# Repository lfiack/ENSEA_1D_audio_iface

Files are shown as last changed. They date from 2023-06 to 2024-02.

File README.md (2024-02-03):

# ENSEA_1D_audio_iface
Interface audio (carte son) pour les TP de systèmes numériques en 1D à l'ENSEA

## Make the project work
This project uses a submodule for the KiCAD library. To get it properly, use the `--recursive` option when cloning the repo :
```
git clone --recursive git@github.com:lfiack/ENSEA_1D_audio_iface.git
```

If you forgot the `--recursive` option (as I do quite often), you can type the following command :
```
git submodule update --init --recursive
```

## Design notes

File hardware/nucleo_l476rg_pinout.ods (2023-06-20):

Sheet: Pinout
101 | PC10 | 102 | PC11 | 201 | PC9 | 202 | PC8
103 | PC12 | 104 | PD2 | 203 | PB8 | 204 | PC6
105 | VDD | 106 | E5V | 205 | PB9 | 206 | PC5
107 | BOOT0 | 108 | GND | 207 | AVDD | 208 | U5V
109 | NC | 110 | NC | 209 | GND | 210 | NC
111 | NC | 112 | IOREF | 211 | PA5 | 212 | PA12
113 | PA13 | 114 | RESET | 213 | PA6 | 214 | PA11
115 | PA14 | 116 | +3V3 | 215 | PA7 | 216 | PB12
117 | PA15 | 118 | +5V | 217 | PB6 | 218 | PB11
119 | GND | 120 | GND | 219 | PC7 | 220 | GND
121 | PB7 | 122 | GND | 221 | PA9 | 222 | PB2
123 | PC13 | 124 | VIN | 223 | PA8 | 224 | PB1
125 | PC14 | 126 | NC | 225 | PB10 | 226 | PB15
127 | PC15 | 128 | PA0 | 227 | PB4 | 228 | PB14
129 | PH0 | 130 | PA1 | 229 | PB5 | 230 | PB13
131 | PH1 | 132 | PA4 | 231 | PB3 | 232 | AGND
133 | VBAT | 134 | PB0 | 233 | PA10 | 234 | PC4
135 | PC2 | 136 | PC1 | 235 | PA2 | 236 | NC
137 | PC3 | 138 | PC0 | 237 | PA3 | 238 | NC

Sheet: Sorted
116 | +3V3
118 | +5V
232 | AGND
207 | AVDD
107 | BOOT0
106 | E5V
108 | GND
119 | GND
120 | GND
122 | GND
209 | GND
220 | GND
112 | IOREF
114 | RESET
208 | U5V
133 | VBAT
105 | VDD
124 | VIN
109 | NC
110 | NC
111 | NC
126 | NC
210 | NC
236 | NC
238 | NC
128 | PA0
130 | PA1
235 | PA2
237 | PA3
132 | PA4
211 | PA5
213 | PA6
215 | PA7
223 | PA8
221 | PA9
233 | PA10
214 | PA11
212 | PA12
113 | PA13
115 | PA14
117 | PA15
134 | PB0
224 | PB1
222 | PB2
231 | PB3
227 | PB4
229 | PB5
217 | PB6
121 | PB7
203 | PB8
205 | PB9
225 | PB10
218 | PB11
216 | PB12
230 | PB13
228 | PB14
226 | PB15
138 | PC0
136 | PC1
135 | PC2
137 | PC3
234 | PC4
206 | PC5
204 | PC6
219 | PC7
202 | PC8
201 | PC9
101 | PC10
102 | PC11
103 | PC12
123 | PC13
125 | PC14
127 | PC15
104 | PD2
129 | PH0
131 | PH1

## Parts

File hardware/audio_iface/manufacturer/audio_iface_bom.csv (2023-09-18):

Designator | Comment | Footprint | LCSC Part #
R301, R401, R402 | 5.1k | Resistor_SMD:R_0402_1005Metric | C2906948
D506, D507, D514, D515 | ORANGE | LED_SMD:LED_0603_1608Metric | C965801
U301 | SGTL5000XNAA3 | Package_DFN_QFN:QFN-32-1EP_5x5mm_P0.5mm_EP3.6x3.6mm | C511764
J303 | HP | Connector_Audio:Jack_3.5mm_PJ320D_Horizontal | C431535
J302 | LINEOUT | Connector_Audio:Jack_3.5mm_PJ320D_Horizontal | C431535
J301 | LINEIN | Connector_Audio:Jack_3.5mm_PJ320D_Horizontal | C431535
J401 | USB_C_Receptacle_USB2.0 | Connector_USB:USB_C_Receptacle_HRO_TYPE-C-31-M-12 | C165948
U501 | MCP23S17-E/SO | Package_SO:SOIC-28W_7.5x17.9mm_P1.27mm | C145413
D501, D502, D503, D504, D505, D509, D510, D511, D512, D513 | GREEN | LED_SMD:LED_0603_1608Metric | C72043
C301, C302, C304, C309, C310, C311, C312 | 1uF | Capacitor_SMD:C_0603_1608Metric | C15849
U401 | USBLC6-2SC6 | Package_TO_SOT_SMD:SOT-23-6 | C7519
D508, D516 | RED | LED_SMD:LED_0603_1608Metric | C2286
C303, C305, C306, C307, C308, C501 | 100nF | Capacitor_SMD:C_0402_1005Metric | C1525
U201 | NUCLEO_L476RG | WITNS:ST_NUCLEO_64
TP307 | HP GND | Connector_Pin:Pin_D1.1mm_L8.5mm_W2.5mm_FlatFork
TP303, TP305, TP308 | L | Connector_Pin:Pin_D1.1mm_L8.5mm_W2.5mm_FlatFork
TP302, TP304, TP306 | R | Connector_Pin:Pin_D1.1mm_L8.5mm_W2.5mm_FlatFork
TP301 | MIC | Connector_Pin:Pin_D1.1mm_L8.5mm_W2.5mm_FlatFork
TP205 | GND | Connector_Pin:Pin_D1.1mm_L8.5mm_W2.5mm_FlatFork
TP204 | TX | Connector_Pin:Pin_D1.1mm_L8.5mm_W2.5mm_FlatFork
TP203 | RX | Connector_Pin:Pin_D1.1mm_L8.5mm_W2.5mm_FlatFork
TP202 | +3.3VA | Connector_Pin:Pin_D1.1mm_L8.5mm_W2.5mm_FlatFork
TP201 | +3.3V | Connector_Pin:Pin_D1.1mm_L8.5mm_W2.5mm_FlatFork
TP112 | SDA | Connector_Pin:Pin_D1.1mm_L8.5mm_W2.5mm_FlatFork
TP111 | SCL | Connector_Pin:Pin_D1.1mm_L8.5mm_W2.5mm_FlatFork
TP110 | DOUT | Connector_Pin:Pin_D1.1mm_L8.5mm_W2.5mm_FlatFork
TP109 | DIN | Connector_Pin:Pin_D1.1mm_L8.5mm_W2.5mm_FlatFork
TP108 | LRCLK | Connector_Pin:Pin_D1.1mm_L8.5mm_W2.5mm_FlatFork
TP107 | SCLK | Connector_Pin:Pin_D1.1mm_L8.5mm_W2.5mm_FlatFork
TP106 | MCLK | Connector_Pin:Pin_D1.1mm_L8.5mm_W2.5mm_FlatFork
TP105 | nCS | Connector_Pin:Pin_D1.1mm_L8.5mm_W2.5mm_FlatFork
TP104 | SCK | Connector_Pin:Pin_D1.1mm_L8.5mm_W2.5mm_FlatFork
TP103 | MOSI | Connector_Pin:Pin_D1.1mm_L8.5mm_W2.5mm_FlatFork
TP102 | MISO | Connector_Pin:Pin_D1.1mm_L8.5mm_W2.5mm_FlatFork
TP101 | nRESET | Connector_Pin:Pin_D1.1mm_L8.5mm_W2.5mm_FlatFork
R506, R507, R508, R514, R515, R516 | 680 | Resistor_SMD:R_0603_1608Metric
R501, R502, R503, R504, R505, R509, R510, R511, R512, R513 | 560 | Resistor_SMD:R_0603_1608Metric
R302, R303 | 1.5k | Resistor_SMD:R_0402_1005Metric
MK301 | Microphone | WITNS:Electret_ABM-713-RC
J201 | UART | Connector_JST:JST_XH_S3B-XH-A_1x03_P2.50mm_Horizontal

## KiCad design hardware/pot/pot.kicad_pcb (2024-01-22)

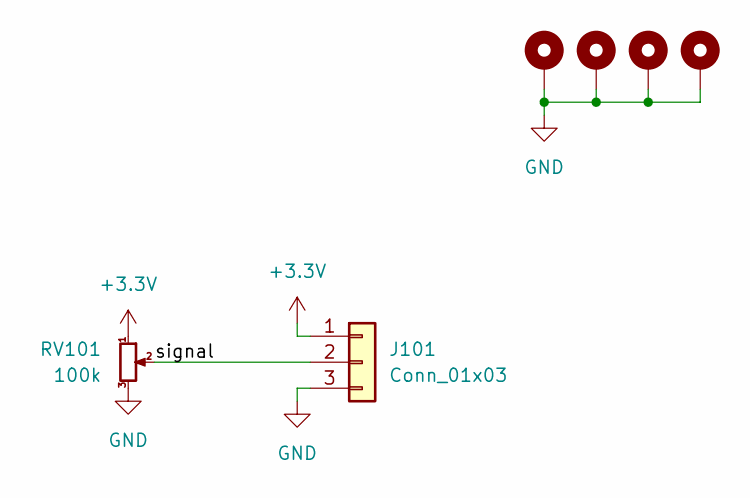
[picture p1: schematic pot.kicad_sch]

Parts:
H101, H102, H103, H104: MountingHole_Pad; MountingHole_3.2mm_M3_Pad
J101: Conn_01x03; JST_XH_S3B-XH-A-1_1x03_P2.50mm_Horizontal
RV101: 100k; Potentiometer_Alpha_RD901F-40-00D_Single_Vertical

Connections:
+3.3V: J101.1, RV101.1
/signal: J101.2, RV101.2
GND: H101.1, H102.1, H103.1, H104.1, J101.3, RV101.3

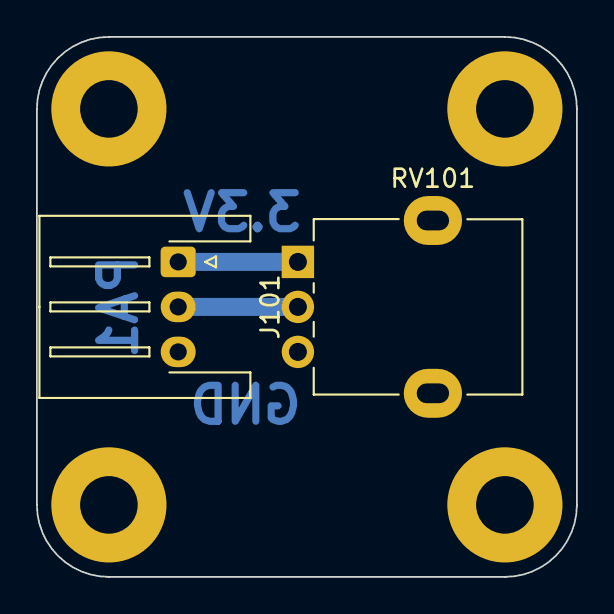
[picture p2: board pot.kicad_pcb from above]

Board: 2 copper layers, 30.0 x 30.0 mm, 6 parts (0 on the bottom side), 3 nets.

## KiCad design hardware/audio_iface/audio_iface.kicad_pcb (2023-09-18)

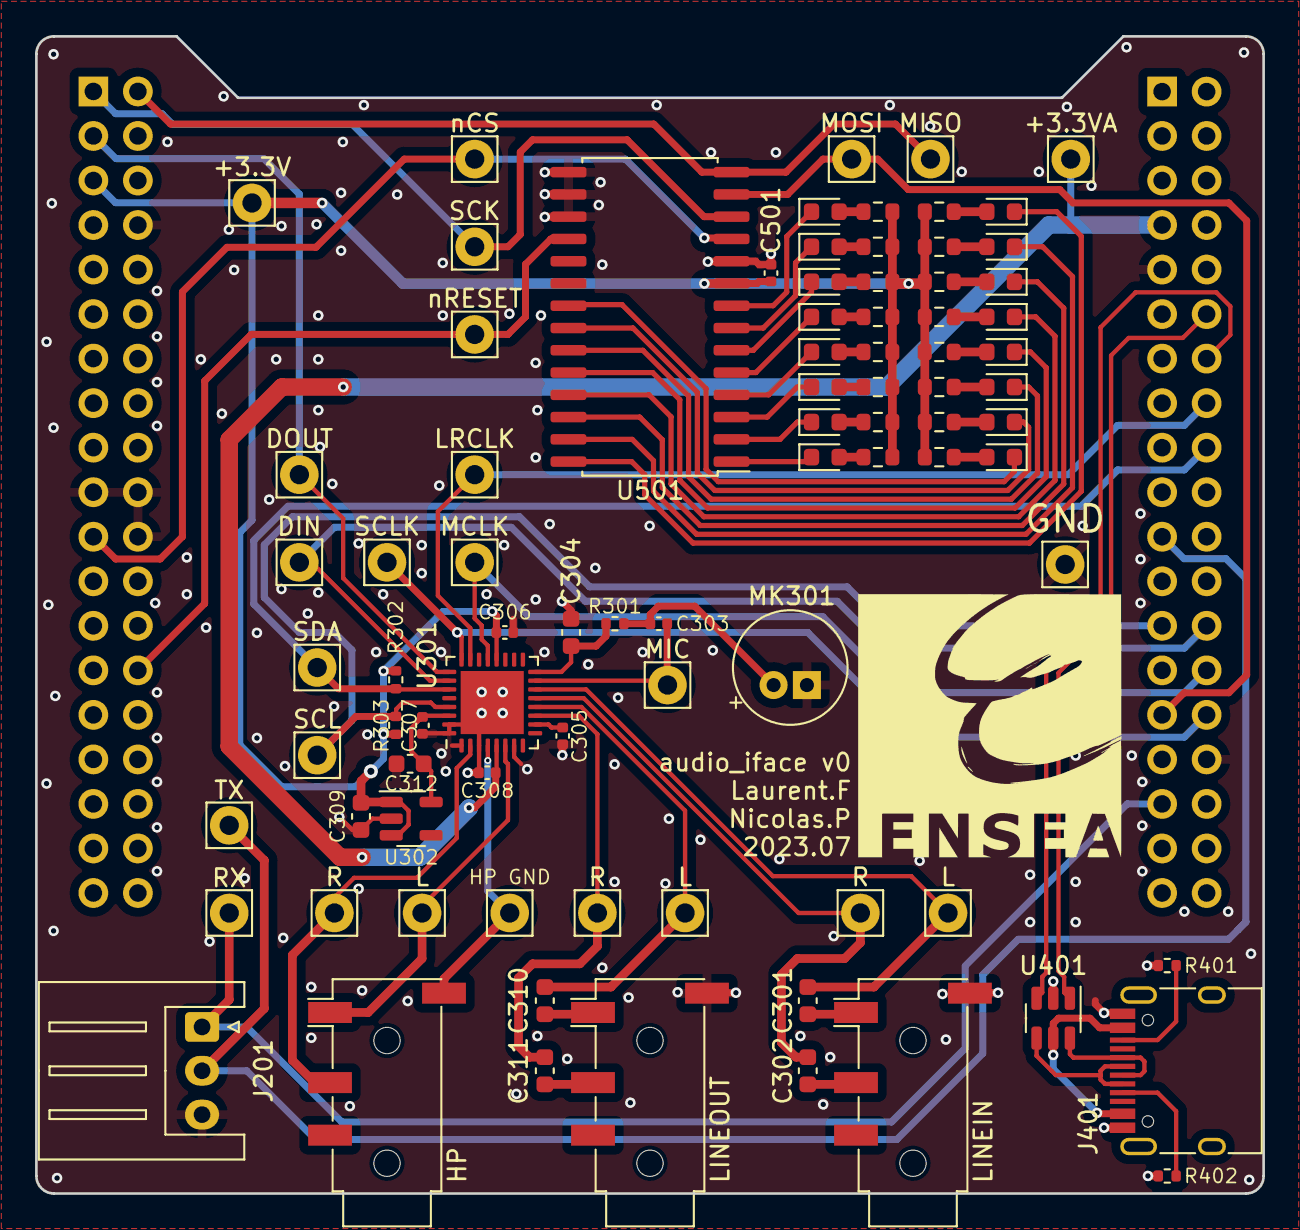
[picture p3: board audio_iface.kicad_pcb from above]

Board: 2 copper layers, 70.0 x 66.0 mm, 86 parts (0 on the bottom side), 72 nets.

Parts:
C301, C302, C304, C310, C311: 1uF; C_0603_1608Metric
C303, C305, C306, C307, C308, C501: 100nF; C_0402_1005Metric
C309, C312: 1u; C_0603_1608Metric
D501, D502, D503, D504, D505, D509, D510, D511, D512, D513: GREEN; LED_0603_1608Metric
D506, D507, D514, D515: ORANGE; LED_0603_1608Metric
D508, D516: RED; LED_0603_1608Metric
J201: UART; JST_XH_S3B-XH-A_1x03_P2.50mm_Horizontal
J301: LINEIN; Jack_3.5mm_PJ320D_Horizontal
J302: LINEOUT; Jack_3.5mm_PJ320D_Horizontal
J303: HP; Jack_3.5mm_PJ320D_Horizontal
J401: USB_C_Receptacle_USB2.0; USB_C_Receptacle_HRO_TYPE-C-31-M-12
MK301: Microphone; Electret_ABM-713-RC
R301, R401, R402: 5.1k; R_0402_1005Metric
R302, R303: 1.5k; R_0402_1005Metric
R501, R502, R503, R504, R505, R506, R507, R508, R509, R510, R511, R512, R513, R514, R515, R516: R_Small; R_0603_1608Metric
TP101: nRESET; Pin_D1.1mm_L8.5mm_W2.5mm_FlatFork
TP102: MISO; Pin_D1.1mm_L8.5mm_W2.5mm_FlatFork
TP103: MOSI; Pin_D1.1mm_L8.5mm_W2.5mm_FlatFork
TP104: SCK; Pin_D1.1mm_L8.5mm_W2.5mm_FlatFork
TP105: nCS; Pin_D1.1mm_L8.5mm_W2.5mm_FlatFork
TP106: MCLK; Pin_D1.1mm_L8.5mm_W2.5mm_FlatFork
TP107: SCLK; Pin_D1.1mm_L8.5mm_W2.5mm_FlatFork
TP108: LRCLK; Pin_D1.1mm_L8.5mm_W2.5mm_FlatFork
TP109: DIN; Pin_D1.1mm_L8.5mm_W2.5mm_FlatFork
TP110: DOUT; Pin_D1.1mm_L8.5mm_W2.5mm_FlatFork
TP111: SCL; Pin_D1.1mm_L8.5mm_W2.5mm_FlatFork
TP112: SDA; Pin_D1.1mm_L8.5mm_W2.5mm_FlatFork
TP201: +3.3V; Pin_D1.1mm_L8.5mm_W2.5mm_FlatFork
TP202: +3.3VA; Pin_D1.1mm_L8.5mm_W2.5mm_FlatFork
TP203: RX; Pin_D1.1mm_L8.5mm_W2.5mm_FlatFork
TP204: TX; Pin_D1.1mm_L8.5mm_W2.5mm_FlatFork
TP205: GND; Pin_D1.1mm_L8.5mm_W2.5mm_FlatFork
TP301: MIC; Pin_D1.1mm_L8.5mm_W2.5mm_FlatFork
TP302, TP304, TP306: R; Pin_D1.1mm_L8.5mm_W2.5mm_FlatFork
TP303, TP305, TP308: L; Pin_D1.1mm_L8.5mm_W2.5mm_FlatFork
TP307: HP GND; Pin_D1.1mm_L8.5mm_W2.5mm_FlatFork
U201: NUCLEO_L476RG; ST_NUCLEO_64
U301: SGTL5000XNAA3; QFN-32-1EP_5x5mm_P0.5mm_EP3.6x3.6mm
U302: BU18SD2MG-MTR; SOT-23-5
U401: USBLC6-2SC6; SOT-23-6
U501: MCP23S17-E/SO; SOIC-28W_7.5x17.9mm_P1.27mm

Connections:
+1V8: C307.1, C312.1, U301.30 (VDDD), U302.5 (OUT)
+3.3V: C306.1, C309.1, C501.1, R302.1, R303.1, R501.2, R502.2, R503.2, R504.2, R505.2, R506.2, R507.2, R508.2, R509.2, R510.2, R511.2, R512.2, R513.2, R514.2, R515.2, R516.2, TP201.1, U201.105 (VDD), U301.20 (VDDIO), U302.1 (IN), U302.3 (STBY), U501.9 (VDD)
+3.3VA: C308.1, TP202.1, U201.207 (AVDD), U301.5 (VDDA)
/AUDIO CODEC/HP_L: J303.T, TP308.1, U301.6 (HP_L)
/AUDIO CODEC/HP_R: J303.R1, TP306.1, U301.2 (HP_R)
/AUDIO CODEC/HP_VGND: J303.S, TP307.1, U301.4 (HP_VGND)
/AUDIO CODEC/I2C_SCL: R303.2, TP111.1, U201.225 (PB10), U301.29 (CTRL_CLK)
/AUDIO CODEC/I2C_SDA: R302.2, TP112.1, U201.218 (PB11), U301.27 (CTRL_DATA)
/AUDIO CODEC/I2S_DIN: TP109.1, U201.226 (PB15), U301.26 (I2S_DIN)
/AUDIO CODEC/I2S_DOUT: TP110.1, U201.103 (PC12), U301.25 (I2S_DOUT)
/AUDIO CODEC/I2S_LRCLK: TP108.1, U201.216 (PB12), U301.23 (I2S_LRCLK)
/AUDIO CODEC/I2S_SCLK: TP107.1, U201.230 (PB13), U301.24 (I2S_SCLK)
/AUDIO CODEC/LINEIN_L: C301.2, TP303.1, U301.14 (LINEIN_L)
/AUDIO CODEC/LINEIN_R: C302.2, TP302.1, U301.13 (LINEIN_R)
/AUDIO CODEC/LINEOUT_L: C310.1, TP305.1, U301.12 (LINEOUT_L)
/AUDIO CODEC/LINEOUT_R: C311.1, TP304.1, U301.11 (LINEOUT_R)
/AUDIO CODEC/MIC: C303.2, TP301.1, U301.15 (MIC)
/AUDIO CODEC/MIC_BIAS: C304.2, R301.2, U301.16 (MIC_BIAS)
/AUDIO CODEC/SYS_MCLK: TP106.1, U201.228 (PB14), U301.21 (SYS_MCLK)
/AUDIO CODEC/VAG: C305.1, U301.10 (VAG)
/NUCLEO/UART_RX: J201.1, TP203.1, U201.233 (PA10)
/NUCLEO/UART_TX: J201.2, TP204.1, U201.221 (PA9)
/NUCLEO/USB_D+: U201.212 (PA12), U401.1 (I/O1)
/NUCLEO/USB_D-: U201.214 (PA11), U401.3 (I/O2)
/NUCLEO/VU_MISO: TP102.1, U201.102 (PC11), U501.14 (SO)
/NUCLEO/VU_MOSI: TP103.1, U201.229 (PB5), U501.13 (SI)
/NUCLEO/VU_SCK: TP104.1, U201.101 (PC10), U501.12 (SCK)
/NUCLEO/VU_nCS: TP105.1, U201.121 (PB7), U501.11 (~CS)
/NUCLEO/VU_nRESET: TP101.1, U201.128 (PA0), U501.18 (~RESET)
/USB/CC1: J401.A5 (CC1), R402.1
/USB/CC2: J401.B5 (CC2), R401.1
/USB/D+: J401.A6 (D+), J401.B6 (D+), U401.6 (I/O1)
/USB/D-: J401.A7 (D-), J401.B7 (D-), U401.4 (I/O2)
/USB/USBC_VBUS: J401.A4 (VBUS), J401.A9 (VBUS), J401.B4 (VBUS), J401.B9 (VBUS), U401.5 (VBUS)
/VU METER/GPA0: D509.1 (K), U501.21 (GPA0)
/VU METER/GPA1: D510.1 (K), U501.22 (GPA1)
/VU METER/GPA2: D511.1 (K), U501.23 (GPA2)
/VU METER/GPA3: D512.1 (K), U501.24 (GPA3)
/VU METER/GPA4: D513.1 (K), U501.25 (GPA4)
/VU METER/GPA5: D514.1 (K), U501.26 (GPA5)
/VU METER/GPA6: D515.1 (K), U501.27 (GPA6)
/VU METER/GPA7: D516.1 (K), U501.28 (GPA7)
/VU METER/GPB0: D501.1 (K), U501.1 (GPB0)
/VU METER/GPB1: D502.1 (K), U501.2 (GPB1)
/VU METER/GPB2: D503.1 (K), U501.3 (GPB2)
/VU METER/GPB3: D504.1 (K), U501.4 (GPB3)
/VU METER/GPB4: D505.1 (K), U501.5 (GPB4)
/VU METER/GPB5: D506.1 (K), U501.6 (GPB5)
/VU METER/GPB6: D507.1 (K), U501.7 (GPB6)
/VU METER/GPB7: D508.1 (K), U501.8 (GPB7)
GND: C304.1, C305.2, C306.2, C307.2, C308.2, C309.2, C312.2, C501.2, J201.3, J301.S, J302.S, J401.A1 (GND), J401.A12 (GND), J401.B1 (GND), J401.B12 (GND), MK301.1 (-), R401.2, R402.2, TP205.1, U201.108 (GND), U201.119 (GND), U201.120 (GND), U201.122 (GND), U201.209 (GND), U201.220 (GND), U201.232 (AGND), U301.1 (GND), U301.3 (GND), U301.7 (AGND), U301.31 (CTRL_ADR0_CS), U301.32 (CTRL_MODE), U301.33 (GND), U302.2 (GND), U401.2 (GND), U501.10 (VSS), U501.15 (A0), U501.16 (A1), U501.17 (A2)
unnamed: C301.1, J301.T
unnamed: C302.1, J301.R1
unnamed: C310.2, J302.T
unnamed: C311.2, J302.R1
unnamed: D501.2 (A), R501.1
unnamed: D502.2 (A), R502.1
unnamed: D503.2 (A), R503.1
unnamed: D504.2 (A), R504.1
unnamed: D505.2 (A), R505.1
unnamed: D506.2 (A), R506.1
unnamed: D507.2 (A), R507.1
unnamed: D508.2 (A), R508.1
unnamed: D509.2 (A), R509.1
unnamed: D510.2 (A), R510.1
unnamed: D511.2 (A), R511.1
unnamed: D512.2 (A), R512.1
unnamed: D513.2 (A), R513.1
unnamed: D514.2 (A), R514.1
unnamed: D515.2 (A), R515.1
unnamed: D516.2 (A), R516.1
unnamed: C303.1, MK301.2 (+), R301.1

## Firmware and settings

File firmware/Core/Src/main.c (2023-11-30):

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
/* Includes ------------------------------------------------------------------*/
#include "main.h"
#include "dma.h"
#include "i2c.h"
#include "sai.h"
#include "spi.h"
#include "usart.h"
#include "usb_device.h"
#include "gpio.h"

/* USER CODE BEGIN Includes */
#include <stdio.h>
#include "sgtl5000.h"

#include "vu_meter.h"
/* USER CODE END Includes */

/* USER CODE BEGIN PD */
#define SAI_TX_BUFFER_LENGTH (48*2)
#define SAI_RX_BUFFER_LENGTH (48*2)
/* USER CODE END PD */


/* USER CODE BEGIN PV */
h_vu_t h_vu;
static int16_t sai_tx_buffer[SAI_TX_BUFFER_LENGTH];
static int16_t sai_rx_buffer[SAI_RX_BUFFER_LENGTH];
/* USER CODE END PV */

void SystemClock_Config(void);
void PeriphCommonClock_Config(void);
/* USER CODE BEGIN 0 */
int _write(int file, char *ptr, int len)
{
	HAL_UART_Transmit(&huart2, (uint8_t*) ptr, len, HAL_MAX_DELAY);

	return len;
}

static int tx_cplt_counter = 0;
void HAL_SAI_TxCpltCallback(SAI_HandleTypeDef *hsai)
{
	if (SAI2_Block_A == hsai->Instance)
	{
		tx_cplt_counter++;
		// TODO Temp juste pour voir
		//HAL_SAI_DMAStop(&hsai_BlockA2);
	}
}

static int tx_half_cplt_counter = 0;
void HAL_SAI_TxHalfCpltCallback(SAI_HandleTypeDef *hsai)
{
	if (SAI2_Block_A == hsai->Instance)
	{
		tx_half_cplt_counter++;
	}
}

static int rx_cplt_flag = 0;
static int rx_cplt_counter = 0;
void HAL_SAI_RxCpltCallback(SAI_HandleTypeDef *hsai)
{
	if (SAI2_Block_B == hsai->Instance)
	{
		rx_cplt_flag = 1;

		for (int i = SAI_RX_BUFFER_LENGTH / 2 ; i < SAI_RX_BUFFER_LENGTH ; i++)
		{
			sai_tx_buffer[i] = sai_rx_buffer[i];
		}

		// TODO Temp juste pour voir
		//HAL_SAI_DMAStop(&hsai_BlockB2);

		rx_cplt_counter++;
	}
}

static int rx_half_cplt_flag = 0;
static int rx_half_cplt_counter = 0;
void HAL_SAI_RxHalfCpltCallback(SAI_HandleTypeDef *hsai)
{
	if (SAI2_Block_B == hsai->Instance)
	{
		rx_half_cplt_flag = 1;

		for (int i = 0 ; i < SAI_RX_BUFFER_LENGTH / 2 ; i++)
		{
			sai_tx_buffer[i] = sai_rx_buffer[i];
		}

		rx_half_cplt_counter++;
	}
}
/* USER CODE END 0 */

/**
 * @brief  The application entry point.
 * @retval int
 */
int main(void)
{
	/* MCU Configuration--------------------------------------------------------*/

	/* Reset of all peripherals, Initializes the Flash interface and the Systick. */
	HAL_Init();

	/* Configure the system clock */
	SystemClock_Config();

	/* Configure the peripherals common clocks */
	PeriphCommonClock_Config();

	/* Initialize all configured peripherals */
	MX_GPIO_Init();
	MX_DMA_Init();
	MX_USART2_UART_Init();
	MX_I2C2_Init();
	MX_SAI2_Init();
	MX_SPI3_Init();
	MX_USART1_UART_Init();
	MX_USB_DEVICE_Init();
	/* Infinite loop */
	/* USER CODE BEGIN WHILE */
	vu_init(&h_vu, &hspi3);
	vu_blink(&h_vu);

	printf("\r\n===== 1DA AUDIO IFACE =====\r\n");

	/**
	 * Configure SYS_FS clock to 48 kHz
	 * Configure MCLK_FREQ to 256*Fs = 12288kHz
	 * PLLSAI1P = 12235.294kHz
	 * FS = PLLSAI1P / 256 = 47.79MHz
	 */

	// Starts MCLK but not the LR clock and other signals
	__HAL_SAI_ENABLE(&hsai_BlockA2);

	/**
	 * For the 32 QFN version of the SGTL5000, the I2C device
	 * address is 0n01010(R/W) where n is determined by
	 * CTRL_ADR0_CS and R/W is the read/write bit from the I2C
	 * protocol.
	 *
	 * CTRL_ADR0_CS is tied to GND
	 * Address is 0001010(R/W)
	 * => 00010100 = 0x14 for Write
	 * => 00010101 = 0x15 for Read
	 * Est-ce que le R/W est ajouté dans la HAL ? Dans ce cas :
	 * => 0001010 = 0x0A -> Eh non!
	 * Cela dit, il rajoute le 1 pour la lecture
	 */

	uint16_t sgtl_address = 0x14;
	uint16_t data;

	h_sgtl5000_t h_sgtl5000;
	h_sgtl5000.hi2c = &hi2c2;
	h_sgtl5000.dev_address = sgtl_address;

	sgtl5000_init(&h_sgtl5000);

	HAL_StatusTypeDef ret;
	ret = sgtl5000_i2c_read_register(&h_sgtl5000, SGTL5000_CHIP_ID, &data);

	if (ret != HAL_OK)
	{
		printf("HAL_I2C_Mem_Read error\r\n");
		Error_Handler();
	}

	for (int i = 0 ; i < SAI_TX_BUFFER_LENGTH ; i++)
	{
		// Generate a sawtooth at 1kHz
		sai_tx_buffer[i] = i * (0xFFFF/SAI_TX_BUFFER_LENGTH);
	}

	printf("Starting SAI...\r\n");
	// Last parameter is the number of DMA CYCLES (here a cycle is 16 bits/2Bytes)
	HAL_SAI_Receive_DMA(&hsai_BlockB2, (uint8_t*) sai_rx_buffer, SAI_RX_BUFFER_LENGTH);
	HAL_SAI_Transmit_DMA(&hsai_BlockA2, (uint8_t*) sai_tx_buffer, SAI_TX_BUFFER_LENGTH);

	/*
	 * Channels are interleaved in the buffer
	 * Bit LR indicate Left/Right Channel
	 * LSB of right channel is presented when LR indicate Left
	 * Same goes for left channel
	 * (SGTL DIN is shifted by 1 bit on the right on the oscilloscope, it's normal for an SAI apparently)
	 */

	int ave_counter = 0;
	int ave = 0;
	int ave_max = 100;

	while (1)
	{
		if (rx_cplt_flag)
		{
			rx_cplt_flag = 0;

			ave += sai_rx_buffer[0];
			ave_counter++;

			if (ave_counter == ave_max)
			{

				ave /= ave_max;
				if (ave < 0) ave = -ave;

				vu_percent(&h_vu, VU_PORTA, ave/5);
				vu_percent(&h_vu, VU_PORTB, ave/5);

				ave = 0;
				ave_counter = 0;
			}
		}
		/* USER CODE END WHILE */

		/* USER CODE BEGIN 3 */
	}
	/* USER CODE END 3 */
}

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


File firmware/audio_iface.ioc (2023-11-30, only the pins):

Mcu.UserName=STM32L476RGTx
PA0.GPIO_Label=VU_nRESET
PA0.Signal=GPIO_Output
PA10.Signal=USART1_RX
PA11.Signal=USB_OTG_FS_DM
PA12.Signal=USB_OTG_FS_DP
PA2.GPIO_Label=USART_TX
PA2.Signal=USART2_TX
PA3.GPIO_Label=USART_RX
PA3.Signal=USART2_RX
PA5.GPIO_Label=LD2 [green Led]
PA5.Signal=GPIO_Output
PA9.Signal=USART1_TX
PB10.Signal=I2C2_SCL
PB11.Signal=I2C2_SDA
PB12.Signal=SAI2_FS_A
PB13.Signal=SAI2_SCK_A
PB14.Signal=SAI2_MCLK_A
PB15.Signal=SAI2_SD_A
PB5.Signal=SPI3_MOSI
PB7.GPIO_Label=VU_nCS
PB7.Signal=GPIO_Output
PC10.Signal=SPI3_SCK
PC11.Signal=SPI3_MISO
PC12.Signal=SAI2_SD_B
PC13.GPIO_Label=B1 [Blue PushButton]
PC13.Signal=GPXTI13
PC4.Signal=USART3_TX
PC5.Signal=USART3_RX

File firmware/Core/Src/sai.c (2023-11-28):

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

/* Includes ------------------------------------------------------------------*/
#include "sai.h"

SAI_HandleTypeDef hsai_BlockA2;
SAI_HandleTypeDef hsai_BlockB2;
DMA_HandleTypeDef hdma_sai2_a;
DMA_HandleTypeDef hdma_sai2_b;

/* SAI2 init function */
void MX_SAI2_Init(void)
{

  hsai_BlockA2.Instance = SAI2_Block_A;
  hsai_BlockA2.Init.AudioMode = SAI_MODEMASTER_TX;
  hsai_BlockA2.Init.Synchro = SAI_ASYNCHRONOUS;
  hsai_BlockA2.Init.OutputDrive = SAI_OUTPUTDRIVE_DISABLE;
  hsai_BlockA2.Init.NoDivider = SAI_MASTERDIVIDER_ENABLE;
  hsai_BlockA2.Init.FIFOThreshold = SAI_FIFOTHRESHOLD_EMPTY;
  hsai_BlockA2.Init.AudioFrequency = SAI_AUDIO_FREQUENCY_48K;
  hsai_BlockA2.Init.SynchroExt = SAI_SYNCEXT_DISABLE;
  hsai_BlockA2.Init.MonoStereoMode = SAI_STEREOMODE;
  hsai_BlockA2.Init.CompandingMode = SAI_NOCOMPANDING;
  hsai_BlockA2.Init.TriState = SAI_OUTPUT_NOTRELEASED;
  if (HAL_SAI_InitProtocol(&hsai_BlockA2, SAI_I2S_STANDARD, SAI_PROTOCOL_DATASIZE_16BIT, 2) != HAL_OK)
  {
    Error_Handler();
  }
  hsai_BlockB2.Instance = SAI2_Block_B;
  hsai_BlockB2.Init.AudioMode = SAI_MODESLAVE_RX;
  hsai_BlockB2.Init.Synchro = SAI_SYNCHRONOUS;
  hsai_BlockB2.Init.OutputDrive = SAI_OUTPUTDRIVE_DISABLE;
  hsai_BlockB2.Init.FIFOThreshold = SAI_FIFOTHRESHOLD_EMPTY;
  hsai_BlockB2.Init.SynchroExt = SAI_SYNCEXT_DISABLE;
  hsai_BlockB2.Init.MonoStereoMode = SAI_STEREOMODE;
  hsai_BlockB2.Init.CompandingMode = SAI_NOCOMPANDING;
  hsai_BlockB2.Init.TriState = SAI_OUTPUT_NOTRELEASED;
  if (HAL_SAI_InitProtocol(&hsai_BlockB2, SAI_I2S_STANDARD, SAI_PROTOCOL_DATASIZE_16BIT, 2) != HAL_OK)
  {
    Error_Handler();
  }
}
static uint32_t SAI2_client =0;

void HAL_SAI_MspInit(SAI_HandleTypeDef* saiHandle)
{

  GPIO_InitTypeDef GPIO_InitStruct;
/* SAI2 */
    if(saiHandle->Instance==SAI2_Block_A)
    {
    /* SAI2 clock enable */
    if (SAI2_client == 0)
    {
       __HAL_RCC_SAI2_CLK_ENABLE();

    /* Peripheral interrupt init*/
    HAL_NVIC_SetPriority(SAI2_IRQn, 0, 0);
    HAL_NVIC_EnableIRQ(SAI2_IRQn);
    }
    SAI2_client ++;

    /**SAI2_A_Block_A GPIO Configuration
    PB12     ------> SAI2_FS_A
    PB13     ------> SAI2_SCK_A
    PB14     ------> SAI2_MCLK_A
    PB15     ------> SAI2_SD_A
    */
    GPIO_InitStruct.Pin = GPIO_PIN_12|GPIO_PIN_13|GPIO_PIN_14|GPIO_PIN_15;
    GPIO_InitStruct.Mode = GPIO_MODE_AF_PP;
    GPIO_InitStruct.Pull = GPIO_NOPULL;
    GPIO_InitStruct.Speed = GPIO_SPEED_FREQ_LOW;
    GPIO_InitStruct.Alternate = GPIO_AF13_SAI2;
    HAL_GPIO_Init(GPIOB, &GPIO_InitStruct);

    /* Peripheral DMA init*/

    hdma_sai2_a.Instance = DMA1_Channel6;
    hdma_sai2_a.Init.Request = DMA_REQUEST_1;
    hdma_sai2_a.Init.Direction = DMA_MEMORY_TO_PERIPH;
    hdma_sai2_a.Init.PeriphInc = DMA_PINC_DISABLE;
    hdma_sai2_a.Init.MemInc = DMA_MINC_ENABLE;
    hdma_sai2_a.Init.PeriphDataAlignment = DMA_PDATAALIGN_HALFWORD;
    hdma_sai2_a.Init.MemDataAlignment = DMA_MDATAALIGN_HALFWORD;
    hdma_sai2_a.Init.Mode = DMA_CIRCULAR;
    hdma_sai2_a.Init.Priority = DMA_PRIORITY_LOW;
    if (HAL_DMA_Init(&hdma_sai2_a) != HAL_OK)
    {
      Error_Handler();
    }

    /* Several peripheral DMA handle pointers point to the same DMA handle.
     Be aware that there is only one channel to perform all the requested DMAs. */
    __HAL_LINKDMA(saiHandle,hdmarx,hdma_sai2_a);
    __HAL_LINKDMA(saiHandle,hdmatx,hdma_sai2_a);
    }
    if(saiHandle->Instance==SAI2_Block_B)
    {
      /* SAI2 clock enable */
      if (SAI2_client == 0)
      {
       __HAL_RCC_SAI2_CLK_ENABLE();

      /* Peripheral interrupt init*/
      HAL_NVIC_SetPriority(SAI2_IRQn, 0, 0);
      HAL_NVIC_EnableIRQ(SAI2_IRQn);
      }
    SAI2_client ++;

    /**SAI2_B_Block_B GPIO Configuration
    PC12     ------> SAI2_SD_B
    */
    GPIO_InitStruct.Pin = GPIO_PIN_12;
    GPIO_InitStruct.Mode = GPIO_MODE_AF_PP;
    GPIO_InitStruct.Pull = GPIO_NOPULL;
    GPIO_InitStruct.Speed = GPIO_SPEED_FREQ_LOW;
    GPIO_InitStruct.Alternate = GPIO_AF13_SAI2;
    HAL_GPIO_Init(GPIOC, &GPIO_InitStruct);

    /* Peripheral DMA init*/

    hdma_sai2_b.Instance = DMA1_Channel7;
    hdma_sai2_b.Init.Request = DMA_REQUEST_1;
    hdma_sai2_b.Init.Direction = DMA_PERIPH_TO_MEMORY;
    hdma_sai2_b.Init.PeriphInc = DMA_PINC_DISABLE;
    hdma_sai2_b.Init.MemInc = DMA_MINC_ENABLE;
    hdma_sai2_b.Init.PeriphDataAlignment = DMA_PDATAALIGN_HALFWORD;
    hdma_sai2_b.Init.MemDataAlignment = DMA_MDATAALIGN_HALFWORD;
    hdma_sai2_b.Init.Mode = DMA_CIRCULAR;
    hdma_sai2_b.Init.Priority = DMA_PRIORITY_LOW;
    if (HAL_DMA_Init(&hdma_sai2_b) != HAL_OK)
    {
      Error_Handler();
    }

    /* Several peripheral DMA handle pointers point to the same DMA handle.
     Be aware that there is only one channel to perform all the requested DMAs. */
    __HAL_LINKDMA(saiHandle,hdmarx,hdma_sai2_b);
    __HAL_LINKDMA(saiHandle,hdmatx,hdma_sai2_b);
    }
}

void HAL_SAI_MspDeInit(SAI_HandleTypeDef* saiHandle)
{

/* SAI2 */
    if(saiHandle->Instance==SAI2_Block_A)
    {
    SAI2_client --;
    if (SAI2_client == 0)
      {
      /* Peripheral clock disable */
       __HAL_RCC_SAI2_CLK_DISABLE();
      HAL_NVIC_DisableIRQ(SAI2_IRQn);
      }

    /**SAI2_A_Block_A GPIO Configuration
    PB12     ------> SAI2_FS_A
    PB13     ------> SAI2_SCK_A
    PB14     ------> SAI2_MCLK_A
    PB15     ------> SAI2_SD_A
    */
    HAL_GPIO_DeInit(GPIOB, GPIO_PIN_12|GPIO_PIN_13|GPIO_PIN_14|GPIO_PIN_15);

    HAL_DMA_DeInit(saiHandle->hdmarx);
    HAL_DMA_DeInit(saiHandle->hdmatx);
    }
    if(saiHandle->Instance==SAI2_Block_B)
    {
    SAI2_client --;
      if (SAI2_client == 0)
      {
      /* Peripheral clock disable */
      __HAL_RCC_SAI2_CLK_DISABLE();
      HAL_NVIC_DisableIRQ(SAI2_IRQn);
      }

    /**SAI2_B_Block_B GPIO Configuration
    PC12     ------> SAI2_SD_B
    */
    HAL_GPIO_DeInit(GPIOC, GPIO_PIN_12);

    HAL_DMA_DeInit(saiHandle->hdmarx);
    HAL_DMA_DeInit(saiHandle->hdmatx);
    }
}

/**
  * @}
  */

/**
  * @}
  */

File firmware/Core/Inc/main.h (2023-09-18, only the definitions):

#define B1_Pin GPIO_PIN_13
#define B1_GPIO_Port GPIOC
#define VU_nRESET_Pin GPIO_PIN_0
#define VU_nRESET_GPIO_Port GPIOA
#define USART_TX_Pin GPIO_PIN_2
#define USART_TX_GPIO_Port GPIOA
#define USART_RX_Pin GPIO_PIN_3
#define USART_RX_GPIO_Port GPIOA
#define LD2_Pin GPIO_PIN_5
#define LD2_GPIO_Port GPIOA
#define TMS_Pin GPIO_PIN_13
#define TMS_GPIO_Port GPIOA
#define TCK_Pin GPIO_PIN_14
#define TCK_GPIO_Port GPIOA
#define SWO_Pin GPIO_PIN_3
#define SWO_GPIO_Port GPIOB
#define VU_nCS_Pin GPIO_PIN_7
#define VU_nCS_GPIO_Port GPIOB

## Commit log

2023-06-20 symbol & footprint
    [audio_codec.kicad_sch, audio_iface.kicad_pcb, audio_iface.kicad_sch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]
2023-06-20 added some connections
    [audio_codec.kicad_sch, audio_iface.kicad_pcb, audio_iface.kicad_sch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]
2023-06-27 Added LEDs
    [audio_codec.kicad_sch, audio_iface.kicad_sch, nucleo.kicad_sch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]
2023-06-28 schematic v1 done
    [audio_codec.kicad_sch, audio_iface.kicad_pcb, audio_iface.kicad_sch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]
2023-06-30 crude placement
    [audio_iface.kicad_pcb, audio_iface.kicad_sch, nucleo.kicad_sch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]
2023-07-03 routing v1
    [audio_codec.kicad_sch, audio_iface.kicad_pcb, nucleo.kicad_sch]
2023-07-17 add logo
    [audio_codec.kicad_sch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]
2023-09-18 First firmware, playing with LEDs
2023-10-02 I2C of SGTL5000 working
2023-11-28 code for ADC not tested
2024-01-22 carte potards
    [pot.kicad_pcb, pot.kicad_sch]

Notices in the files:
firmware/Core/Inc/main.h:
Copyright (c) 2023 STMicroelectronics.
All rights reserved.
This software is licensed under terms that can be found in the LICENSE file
